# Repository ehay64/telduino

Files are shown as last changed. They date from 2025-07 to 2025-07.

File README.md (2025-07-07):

# Telduino

## Summary
Telduino is an Arduino shield for land line telephones. Telduino has the ability to send and receive audio to and from land line telephones, as well as make them ring.

## Background
Over the last few years, I've been collecting interesting land line telephones here and there. Since land line service is nearly defunct as of this writing, I figured it would be neat to have a device that could pipe audio to and from a telephone and, more importantly, make them ring. This culminated in an Arduino shield that can be connected to a telephone.

## Details
The heart of this shield is the KS0835F SLIC (subscriber line interface circuit) module. This module provides all the required voltages, currents, and signals to the telephone. It also provides line level audio input and output. The module itself requires some signaling, which is provided by the Arduino.

The shield has two 3.5mm audio jacks for audio input and output, and a RJ11 jack for the telephone. The Arduino sketch controls ringing of the telephone by controlling the SLIC module.

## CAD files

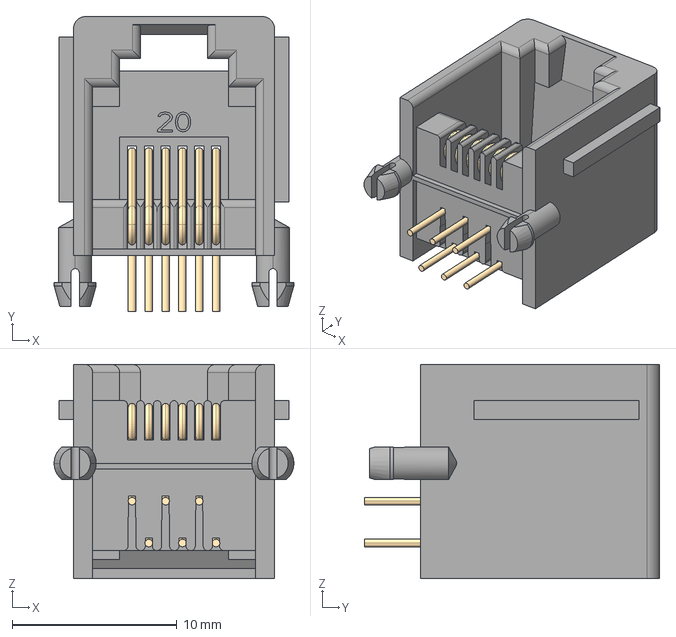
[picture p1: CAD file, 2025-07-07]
MJ3235-66-0_REVA.step
14.5 x 17.9 x 13.0 mm

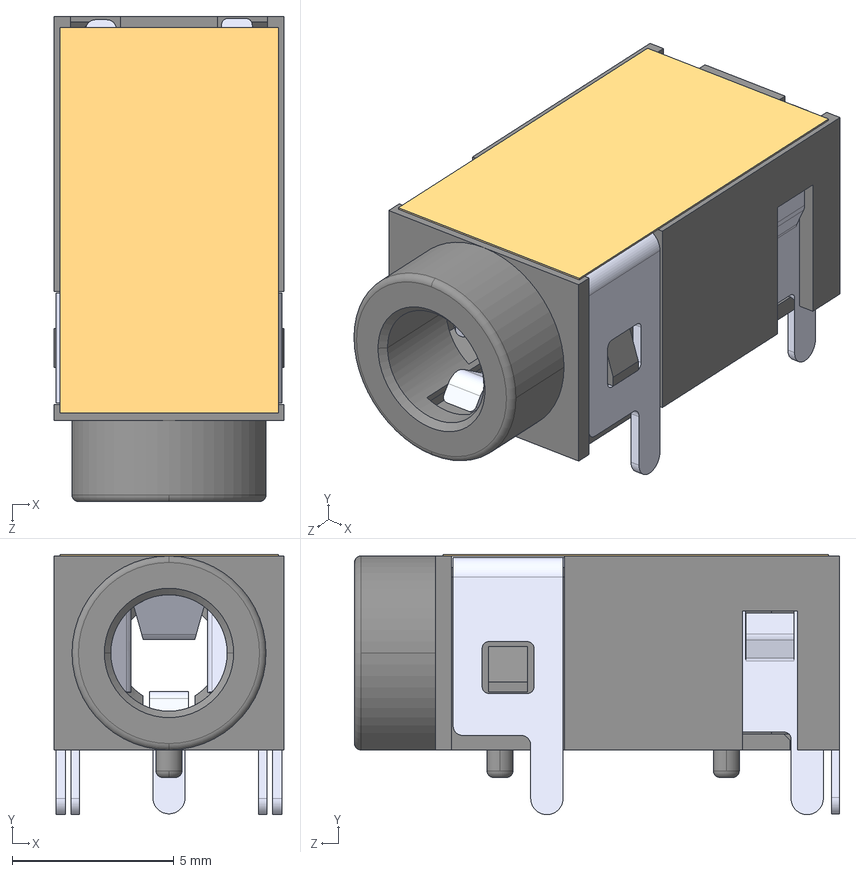
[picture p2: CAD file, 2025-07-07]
54-00174.step
7.10 x 8.05 x 15.0 mm
54-00174_housing
54-00174_#1
54-00174_#3
54-00174_#2
54-00174_#4

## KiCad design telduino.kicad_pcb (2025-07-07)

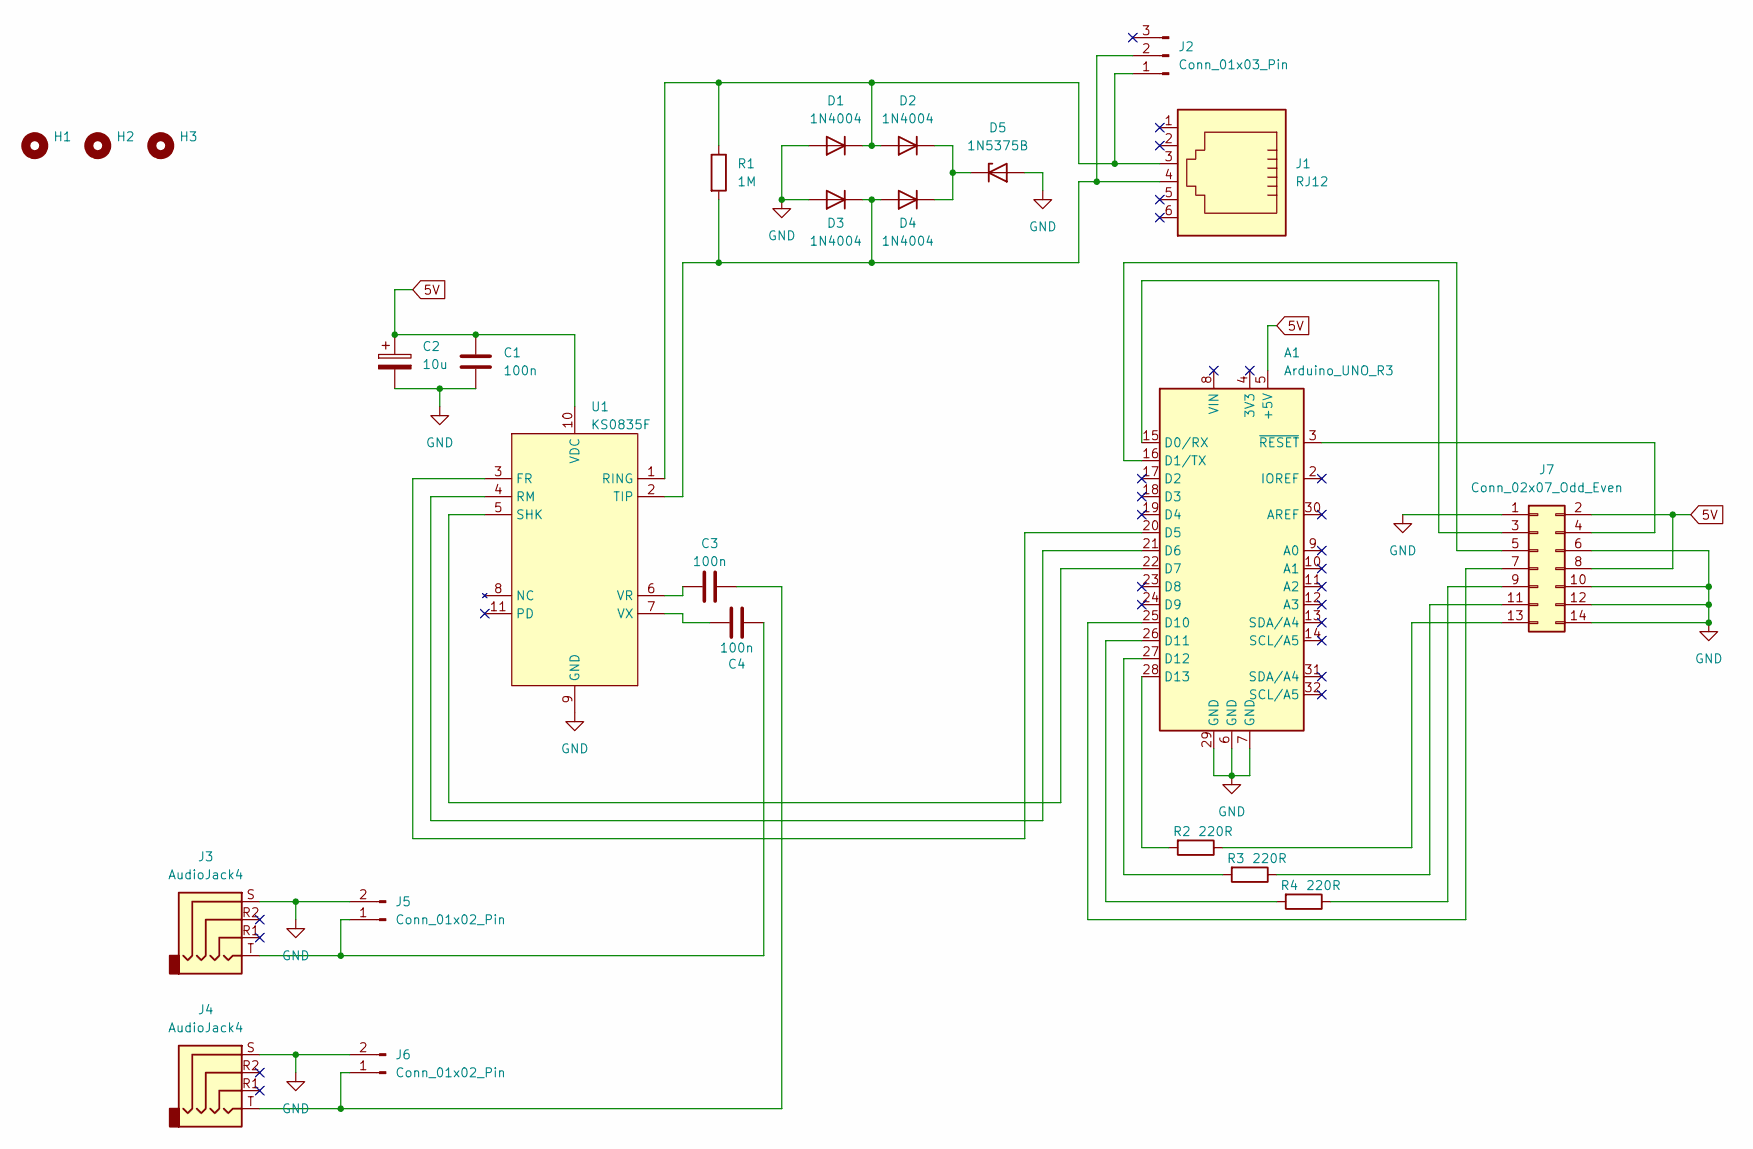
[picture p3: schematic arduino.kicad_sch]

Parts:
A1: Arduino_UNO_R3
C1, C3, C4: 100n; C_0805_2012Metric_Pad1.18x1.45mm_HandSolder
C2: 10u; CP_EIA-3216-18_Kemet-A_Pad1.58x1.35mm_HandSolder
D1, D2, D3, D4: 1N4004; D_DO-41_SOD81_P10.16mm_Horizontal
D5: 1N5375B; D_DO-201_P15.24mm_Horizontal
H1, H2, H3: MountingHole; MountingHole_3.2mm_M3
J1: RJ12; GCT_MJ3235-66-0_REVA
J2: Conn_01x03_Pin; PinHeader_1x03_P2.54mm_Vertical
J3, J4: AudioJack4; TENSILITY_54-00174
J5, J6: Conn_01x02_Pin; PinHeader_1x02_P2.54mm_Vertical
J7: Conn_02x07_Odd_Even; PinHeader_2x07_P2.54mm_Vertical
R1: 1M; R_Axial_DIN0207_L6.3mm_D2.5mm_P10.16mm_Horizontal
R2, R3, R4: 220R; R_0805_2012Metric_Pad1.20x1.40mm_HandSolder
U1: KS0835F

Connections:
5V: A1.5 (+5V), C1.1, C2.1, J7.2, J7.8, U1.10 (VDC)
GND: A1.6 (GND), A1.7 (GND), A1.29 (GND), C1.2, C2.2, D1.2 (A), D3.2 (A), D5.2 (A), J3.S, J4.S, J5.2, J6.2, J7.1, J7.6, J7.10, J7.12, J7.14, U1.9 (GND)
unnamed: A1.15 (D0/RX), J7.3
unnamed: A1.16 (D1/TX), J7.5
unnamed: A1.20 (D5), U1.3 (FR)
unnamed: A1.21 (D6), U1.4 (RM)
unnamed: A1.22 (D7), U1.5 (SHK)
unnamed: A1.25 (D10), J7.7
unnamed: A1.26 (D11), R4.2
unnamed: A1.27 (D12), R3.2
unnamed: A1.28 (D13), R2.2
unnamed: A1.3 (~RESET), J7.4
unnamed: D1.1 (K), D2.2 (A), J1.3, J2.1, R1.1, U1.1 (RING)
unnamed: D2.1 (K), D4.1 (K), D5.1 (K)
unnamed: D3.1 (K), D4.2 (A), J1.4, J2.2, R1.2, U1.2 (TIP)
unnamed: C4.2, J3.T, J5.1
unnamed: C3.2, J4.T, J6.1
unnamed: J7.9, R4.1
unnamed: J7.11, R3.1
unnamed: J7.13, R2.1
unnamed: C3.1, U1.6 (VR)
unnamed: C4.1, U1.7 (VX)

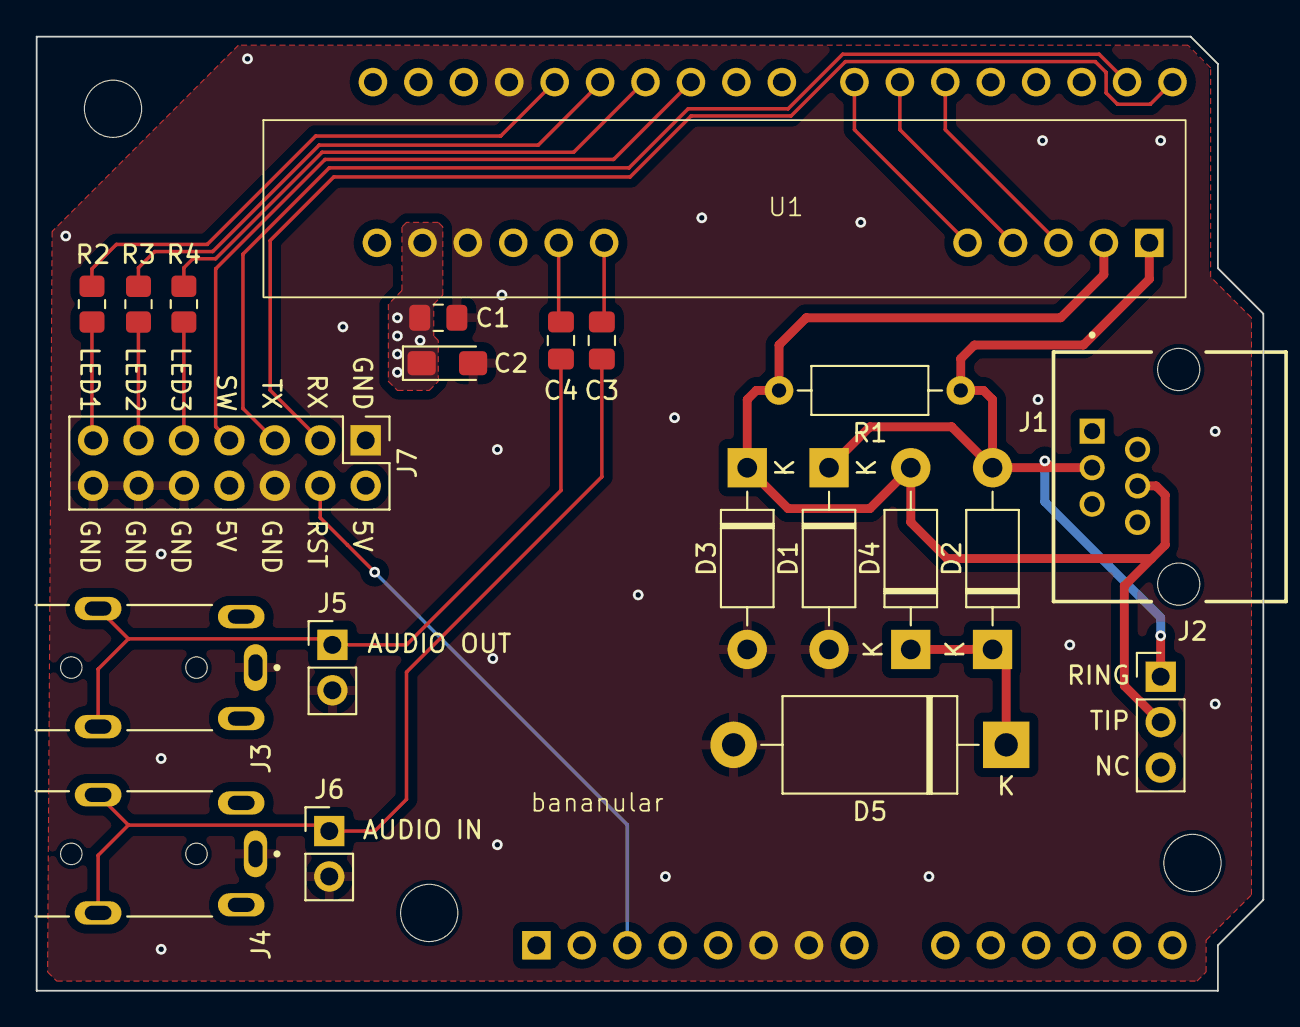
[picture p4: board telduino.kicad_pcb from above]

Board: 2 copper layers, 68.6 x 53.3 mm, 25 parts (0 on the bottom side), 22 nets.
